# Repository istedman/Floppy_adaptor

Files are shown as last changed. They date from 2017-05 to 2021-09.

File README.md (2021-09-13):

# Floppy_adaptor V2.5
Converts PC floppy drive interface to Amiga/Shugart bus interface. Now also supports the Atari ST/TT. Only supports Double Density (DD) disks but works with an HD drive in DD mode.

The native files in EagleCAD format are included. The Zip file contains the Gerber data.
# 2021 Update.
I'm discontinuing sales of all Amiga related projects. Reduced order volumes and extra issues with order post Brexit have not made it viable to continue.
All information, including BOMs, Gerbers and notes are now in the repository, if you want to build your own.

The design supports use as an external drive, see the file External_drive_wiring_V2.png for details.

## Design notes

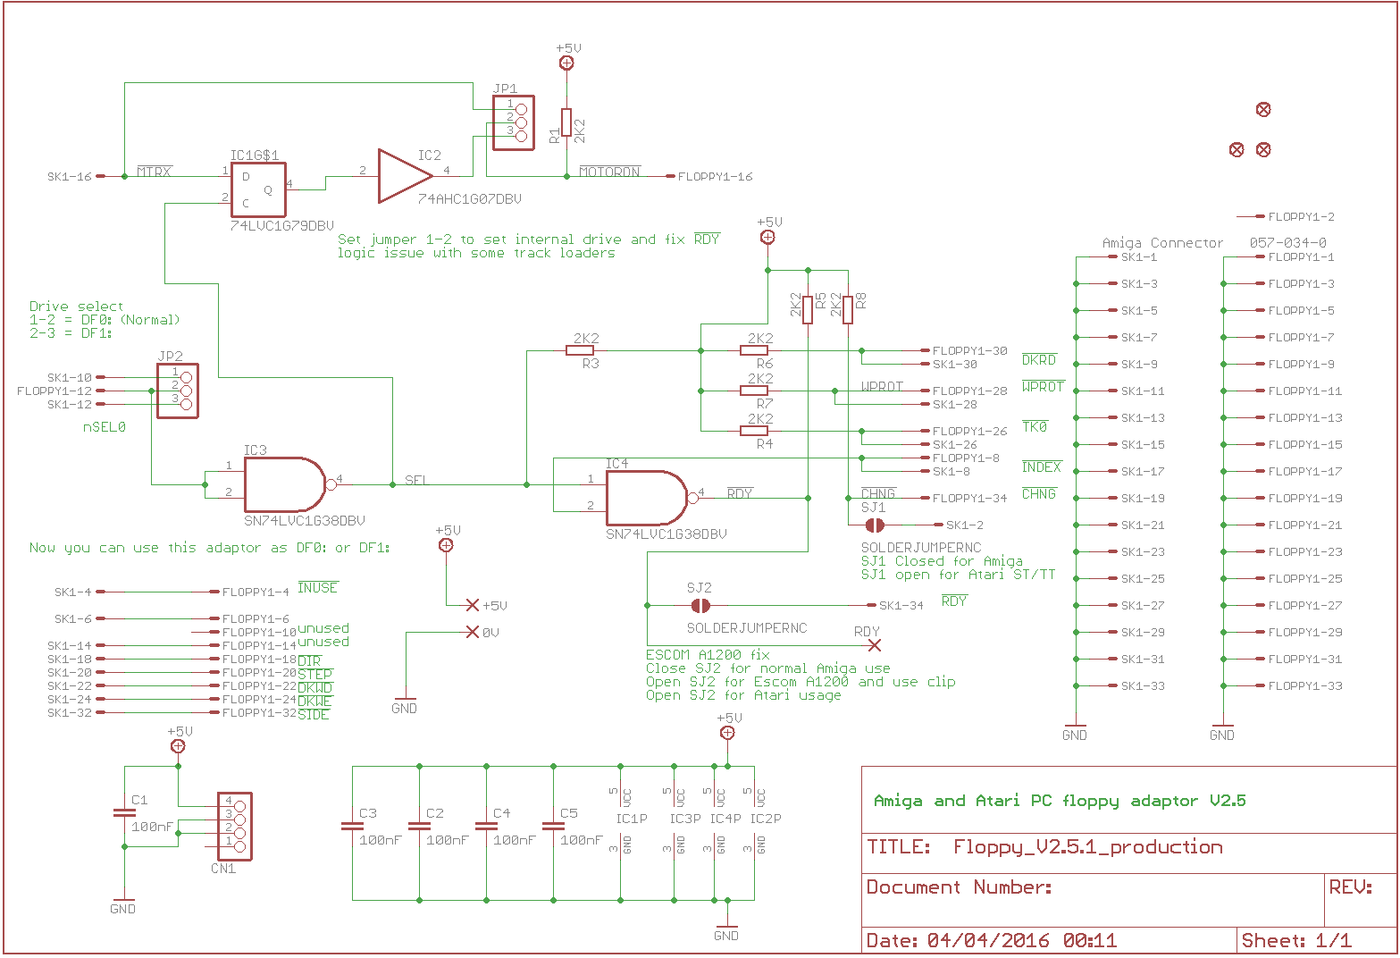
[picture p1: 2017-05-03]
Floppy_v2.5_schematic.png

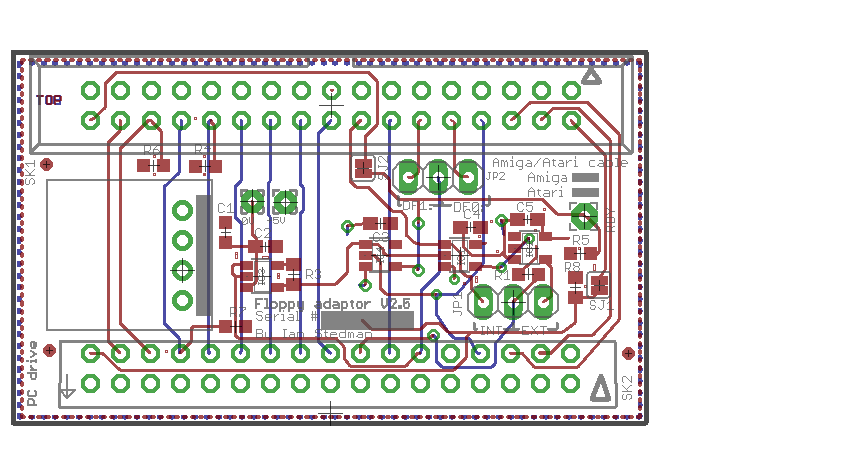
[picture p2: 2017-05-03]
Floppy_v2.5_PCB.png

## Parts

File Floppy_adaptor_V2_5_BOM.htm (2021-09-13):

Floppy adaptor V2.5 BOM |  |  | QTY 75
Line number | Reference | Quantity | Supplier P/N | Description | Farnell P/N | Mouser | Rapid P/N | Quickteck | Unit Price | Total price
1 | C1-C6 | 6 | C0603C104K5RACTU | Capacitor, 100nF, X7R dielectric, 50V, 10% |  | 80-C0603C104K5R |  |  | £0.02 | £0.09
2 | CN1 | 1 | AMP171826-4 floppy power plug, R/A | Floppy power plug, R/A | 1056115 | 571-1718264 |  |  | £0.37 | £0.37
3 | JP1,JP2 | 2 | TruConnect 3W | Pin header, 2.54 mm pitch, 3 way | 1022249 |  | 22-0500 |  | £0.02 | £0.04
4 | SK1 | 1 | Oupiin 3012-34C00SYA | 34 way box header, 2.54mm pitch | 109-9260 |  | 19-0525 |  | £0.24 | £0.24
5 | SK2 | 1 | BKL 10120824 | 2 x 17 Pin Header Angled 2.54mm Pitch 3A Gold Plated |  |  | 50-8132 |  | £0.70 | £0.70
6 | R1-R8 | 8 | CRCW02012K21FKED | 2K2 resistor, 5%, 0603 size |  | 71-CRCW02012K21FKED |  |  | £0.02 | £0.16
7 | IC1 | 1 | SN74LVC1G79DBVR | Little logic 1G79, D-type latch, SOT-23-5 |  | 595-SN74LVC1G79DBVR |  |  | £0.17 | £0.17
8 | IC3, IC4 | 2 | SN74LVC1G38DBVR | Little logic 1G38, O/C NAND, SOT-23-5 |  | 595-SN74LVC1G38DBVR |  |  | £0.10 | £0.19
9 | IC2 | 1 | SN74LVC1G07DBVR | Little logic 1G07, O/C buffer, SOT-23-5 |  | 595-SN74LVC1G07DBVR |  |  | £0.19 | £0.19
10 | PCB | 1 |  | Floppy_adaptor_V2.5 PCB, 54 x 32mm, dual layer |  |  |  | £1.42 | £1.25 | £1.25
 |  |  |  |  |  |  |  |  |  | £0.00
 |  |  |  |  |  |  |  |  |  | £0.00
 |  |  |  |  |  |  |  |  |  | £0.00
 |  |  |  |  |  |  |  |  |  | £0.00
Non PCB parts to order |  |  |  |  |  |  |  |  |  | £0.00
 |  | 2 |  | Shorting jumpers for the two headers | 148-029 |  | 22-0690 |  | £0.03 | £0.06
 |  | 1 | AMP 171824 housing | AMP 171824 housing | 150665 |  |  |  | £0.16 | £0.16
 |  | 2 | AMP 170262-1 Pins for AMP housing | Crimp pins for above housing | 1654691 |  |  |  | £0.06 | £0.12
 |  |  |  |  |  | Assembly by quickteck |  |  | £4.27 | £4.27
 |  |  |  |  |  |  |  | Total EX VAT |  | £8.00

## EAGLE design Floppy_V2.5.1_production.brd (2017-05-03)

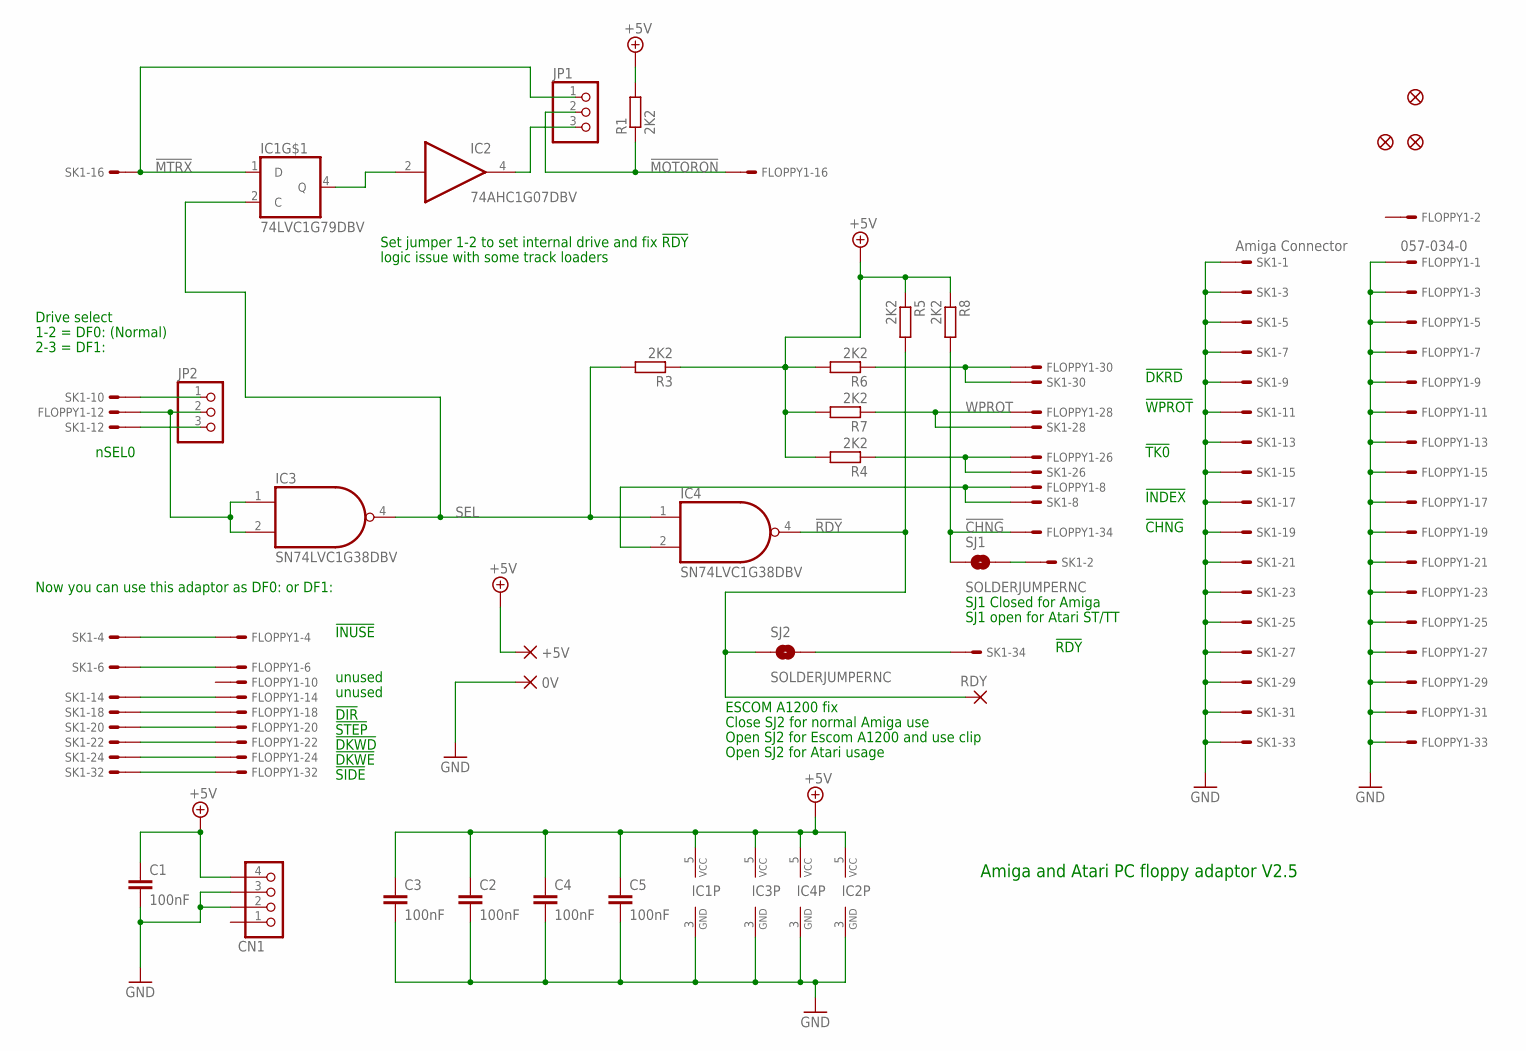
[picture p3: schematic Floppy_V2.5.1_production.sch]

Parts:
0V: PAD-0360-S; 0360-S
+5V: PAD-0360-S; 0360-S
C1, C2, C3, C4, C5: 100nF; C0603
CN1: IANS_FLOPPY_RA; IANS_FLOPPYPOWER__RA
FLOPPY1: 057-034-0
IC1: 74LVC1G79DBV; SOT23-5
IC2: 74AHC1G07DBV; SOT23-5
IC3, IC4: SN74LVC1G38DBV; SOT23-5
JP1, JP2: PINHD-1X3; 1X03
JP3, JP4, JP5: FIDUCIAL1X2; FIDUCIAL-1X2
R1, R3, R4, R5, R6, R7, R8: 2K2; R0603
RDY: 2,15/1,0
SJ1, SJ2: SOLDERJUMPERNC; SJ_2S
SK1: Amiga Connector; 057-034-1

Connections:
!CHNG: FLOPPY1.34, R8.2, SJ1.1
!MOTORON: FLOPPY1.16, JP1.2, R1.1
!MTRX: IC1.1 (D), JP1.1, SK1.16
!RDY: IC4.4 (O), R5.2, RDY.1, SJ2.1
+5V: +5V.P$1, C1.1, C2.1, C3.1, C4.1, C5.1, CN1.4 (+5V), IC1.5 (VCC), IC2.5 (VCC), IC3.5 (VCC), IC4.5 (VCC), R1.2, R3.1, R4.2, R5.1, R6.2, R7.2, R8.1
GND: 0V.P$1, C1.2, C2.2, C3.2, C4.2, C5.2, CN1.2 (GND), CN1.3 (GND), FLOPPY1.1, FLOPPY1.3, FLOPPY1.5, FLOPPY1.7, FLOPPY1.9, FLOPPY1.11, FLOPPY1.13, FLOPPY1.15, FLOPPY1.17, FLOPPY1.19, FLOPPY1.21, FLOPPY1.23, FLOPPY1.25, FLOPPY1.27, FLOPPY1.29, FLOPPY1.31, FLOPPY1.33, IC1.3 (GND), IC2.3 (GND), IC3.3 (GND), IC4.3 (GND), SK1.1, SK1.3, SK1.5, SK1.7, SK1.9, SK1.11, SK1.13, SK1.15, SK1.17, SK1.19, SK1.21, SK1.23, SK1.25, SK1.27, SK1.29, SK1.31, SK1.33
unnamed: IC1.4 (Q), IC2.2 (I)
unnamed: IC2.4 (O), JP1.3
unnamed: FLOPPY1.8, IC4.2 (I1), SK1.8
unnamed: FLOPPY1.26, R4.1, SK1.26
unnamed: FLOPPY1.14, SK1.14
unnamed: FLOPPY1.30, R6.1, SK1.30
unnamed: JP2.1, SK1.10
unnamed: FLOPPY1.12, IC3.1 (I0), IC3.2 (I1), JP2.2
unnamed: JP2.3, SK1.12
unnamed: FLOPPY1.18, SK1.18
unnamed: FLOPPY1.20, SK1.20
unnamed: FLOPPY1.22, SK1.22
unnamed: FLOPPY1.24, SK1.24
unnamed: FLOPPY1.32, SK1.32
unnamed: FLOPPY1.4, SK1.4
unnamed: FLOPPY1.6, SK1.6
unnamed: SJ1.2, SK1.2
unnamed: SJ2.2, SK1.34
SEL: IC1.2 (C), IC3.4 (O), IC4.1 (I0), R3.2
WPROT: FLOPPY1.28, R7.1, SK1.28

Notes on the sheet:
!DKRD
!WPROT
!TK0
!INDEX
nSEL0
!CHNG
!RDY
ESCOM A1200 fix
Close SJ2 for normal Amiga use
Open SJ2 for Escom A1200 and use clip
!INUSE
unused
Amiga and Atari PC floppy adaptor V2.5
Drive select
1-2 = DF0: (Normal)
2-3 = DF1:
Now you can use this adaptor as DF0: or DF1:
Set jumper 1-2 to set internal drive and fix !RDY
logic issue with some track loaders
!DIR
!STEP
!DKWD
!DKWE
!SIDE
SJ1 Closed for Amiga
SJ1 open for Atari ST/TT
Open SJ2 for Atari usage

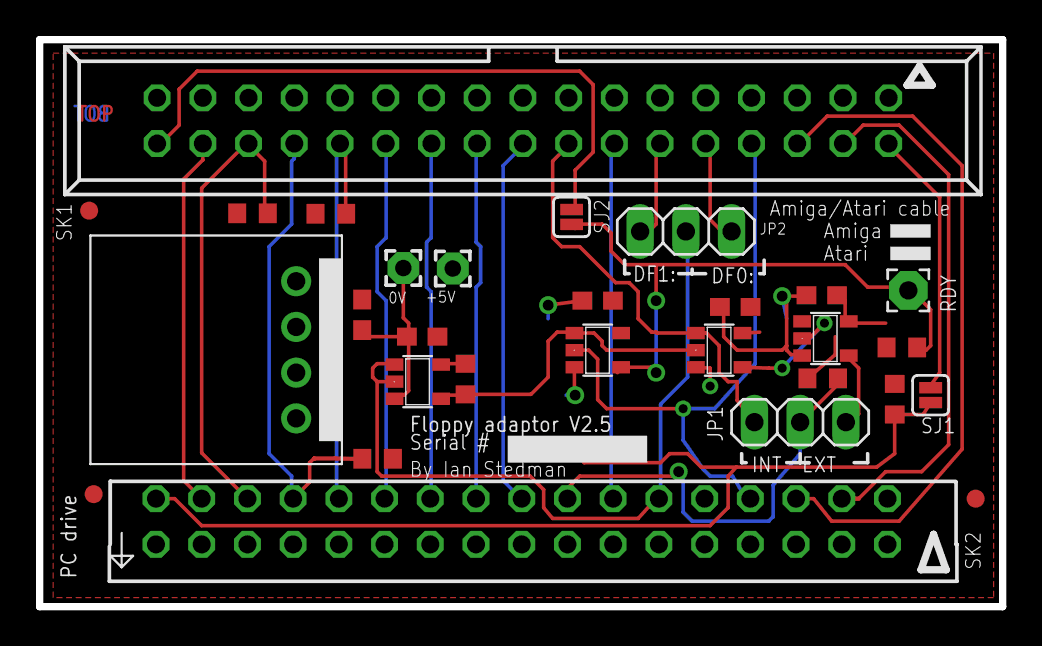
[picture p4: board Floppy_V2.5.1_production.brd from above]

Board: 2 copper layers, 53.5 x 31.5 mm, 29 parts (0 on the bottom side), 26 nets.

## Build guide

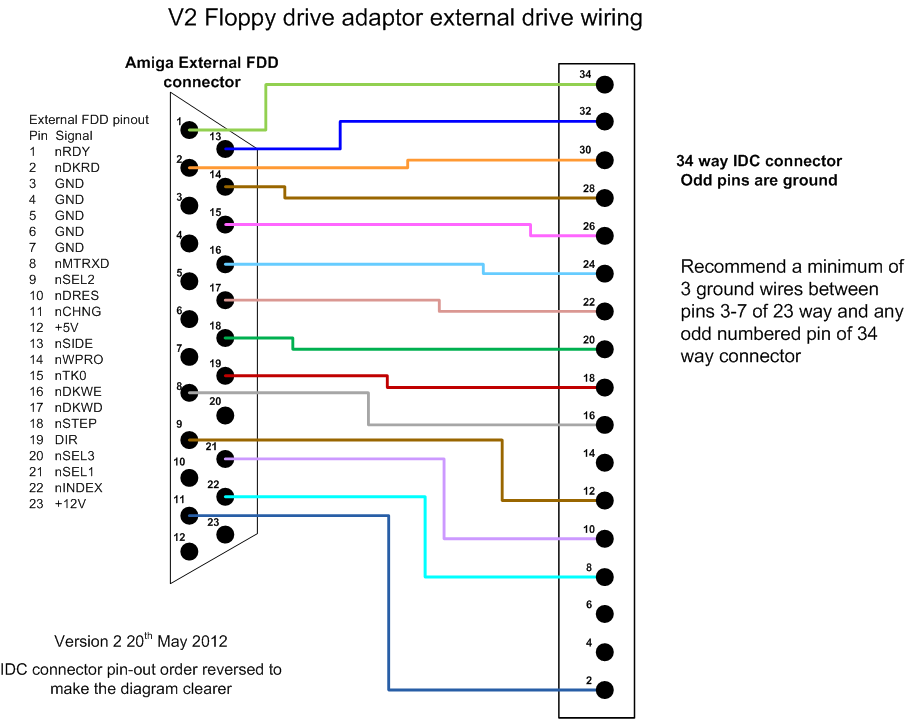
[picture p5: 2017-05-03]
External_drive_wiring_V2.png

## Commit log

2021-09-12 Add files via upload
    Gerber images used for the last production batch.
    [Floppy_V2.5.2_production.gbl, Floppy_V2.5.2_production.gbs, Floppy_V2.5.2_production.gtl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]
2021-09-13 Add files via upload
    Export from Excel of the most recent BOM from Excel used for the last build.
2021-09-14 Add files via upload
    The most recent bill of materials, exported from the Excel master.
